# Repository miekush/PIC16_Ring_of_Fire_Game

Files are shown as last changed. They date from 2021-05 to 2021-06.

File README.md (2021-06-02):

# PIC16_Ring_of_Fire_Game
A PIC16 based LED Reaction Time Game

This is a simple LED reaction time game based on the classes light ring redemption games seen in arcades. 

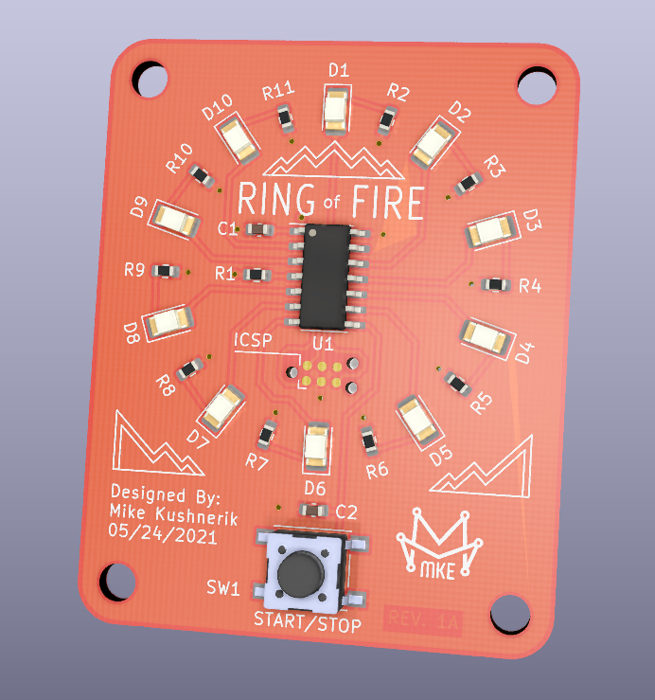
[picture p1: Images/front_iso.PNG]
PCB


# Project Description

The device uses a PIC16F15223 8-bit microcontroller to drive a ring of 1206 LEDs. A low cost tactile switch starts and stops the led chaser and allows for switching between game mode and a speed settings mode depending on the press duration. Programming the device is completed via the onboard Tag-Connect footprint.

# Breadboard Prototype

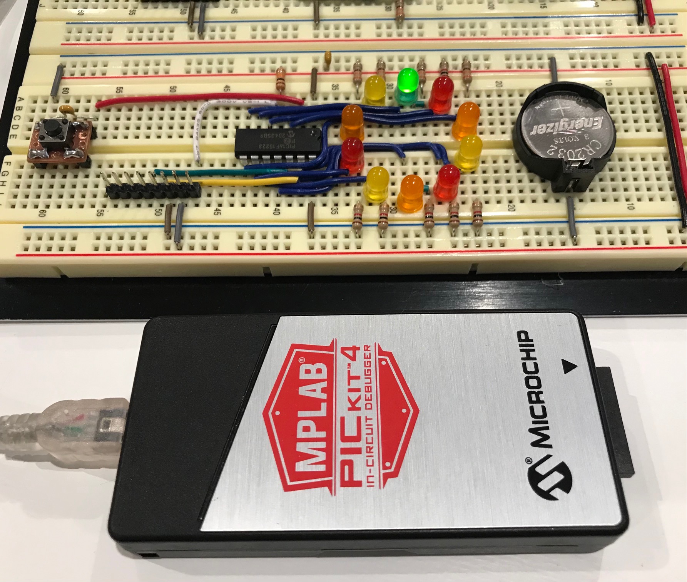
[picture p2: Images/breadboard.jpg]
Breadboard


# Enclosure

To make the device more comfortable for handheld use, I designed a small enclosure which can be easily 3D printed for a more professional device appearence.

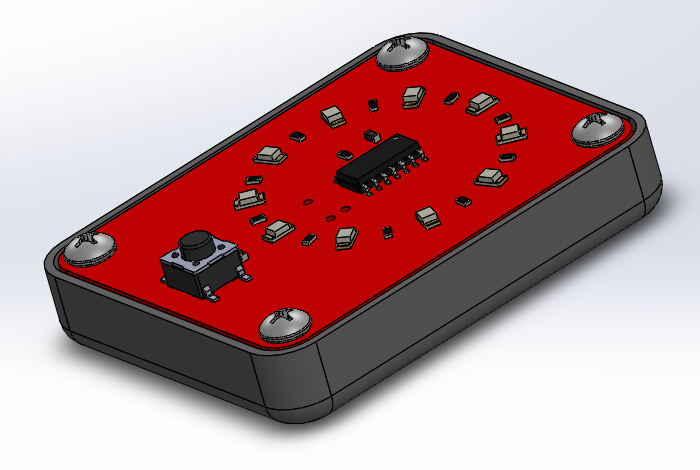
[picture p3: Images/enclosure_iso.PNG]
Enclosure


Designed by Mike Kushnerik (MKE) in KiCad V5

# License

MKE supports the open source hardware community by sharing hardware design files freely on GitHub!

Please support MKE by purchasing products on [Tindie](https://www.tindie.com/stores/mkengineering/)!

Designed by Mike Kushnerik for MKEngineering

Licensed under [Creative Commons Attribution-ShareAlike CC BY-SA 3.0](http://creativecommons.org/licenses/by-sa/3.0/)

All text above must be included in any redistribution!

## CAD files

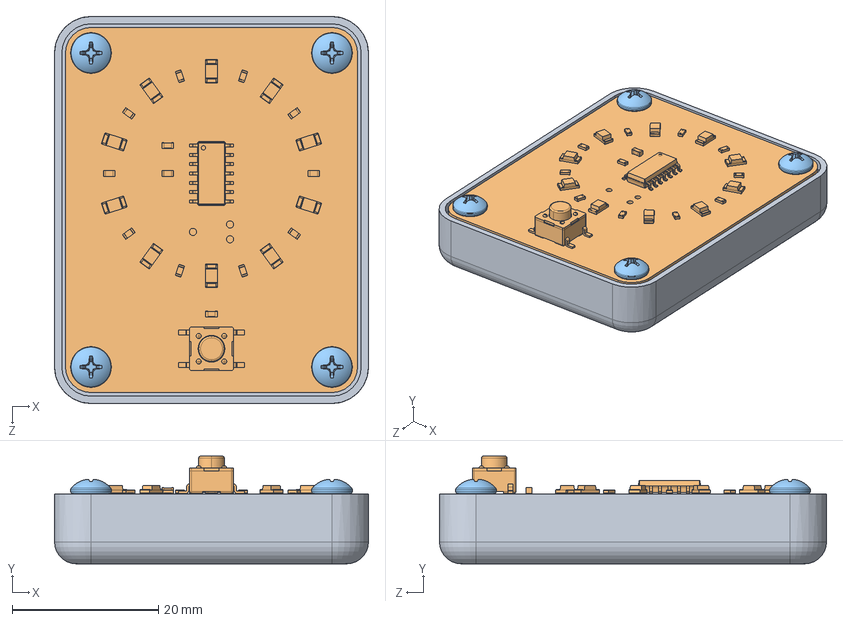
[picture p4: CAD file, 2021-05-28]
Enclosure/Revision 1/ring_of_fire_assembly_rev_1.SLDASM
43.0 x 14.8 x 53.0 mm
ring_of_fire_enclosure
ring_of_fire_pcba_rev_1a
92295A100_PHILLIPS THREAD-FORMING SCREW FOR PLASTIC x 4

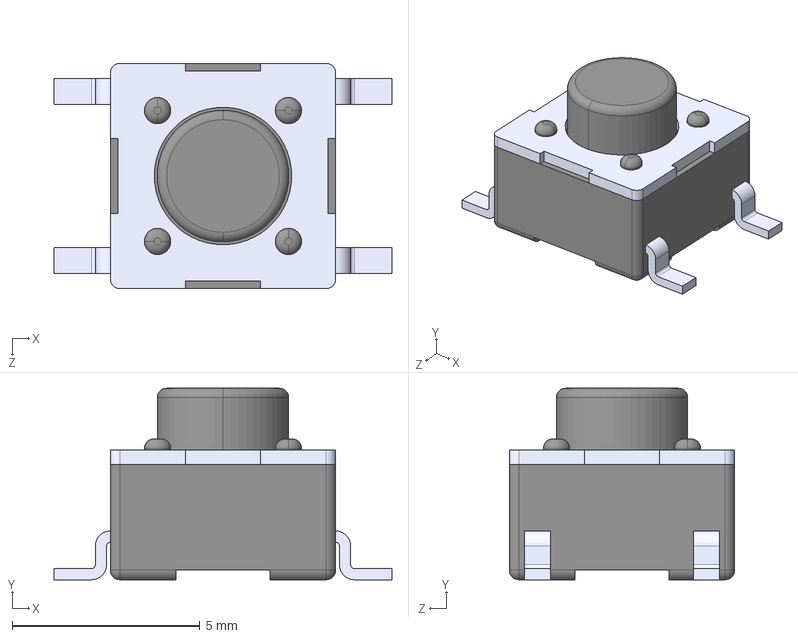
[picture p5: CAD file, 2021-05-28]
3D Models/PTS645SK50SMTR92LFS--3DModel-STEP-1.STEP
9.00 x 5.10 x 6.00 mm

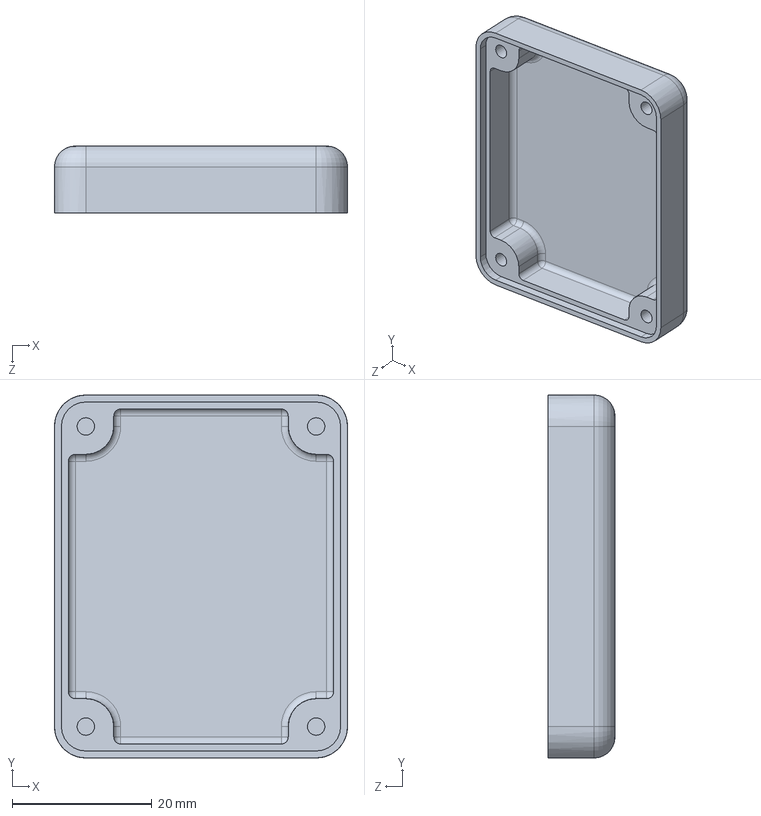
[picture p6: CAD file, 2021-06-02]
Enclosure/Revision 1/ring_of_fire_enclosure.SLDPRT
42.0 x 52.0 x 9.60 mm

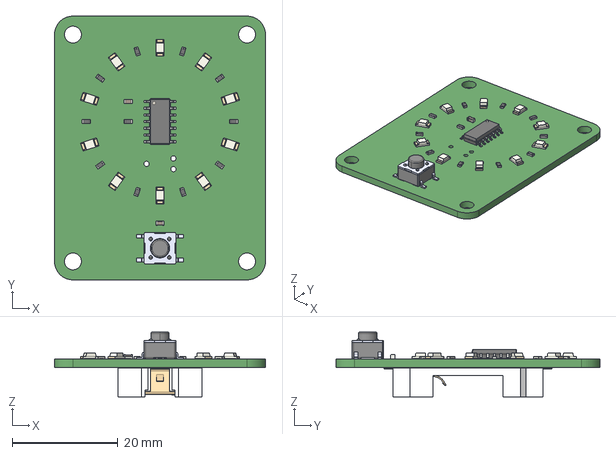
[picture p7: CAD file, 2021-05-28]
Enclosure/ring_of_fire_pcba_rev_1a.step
40.0 x 50.0 x 12.3 mm

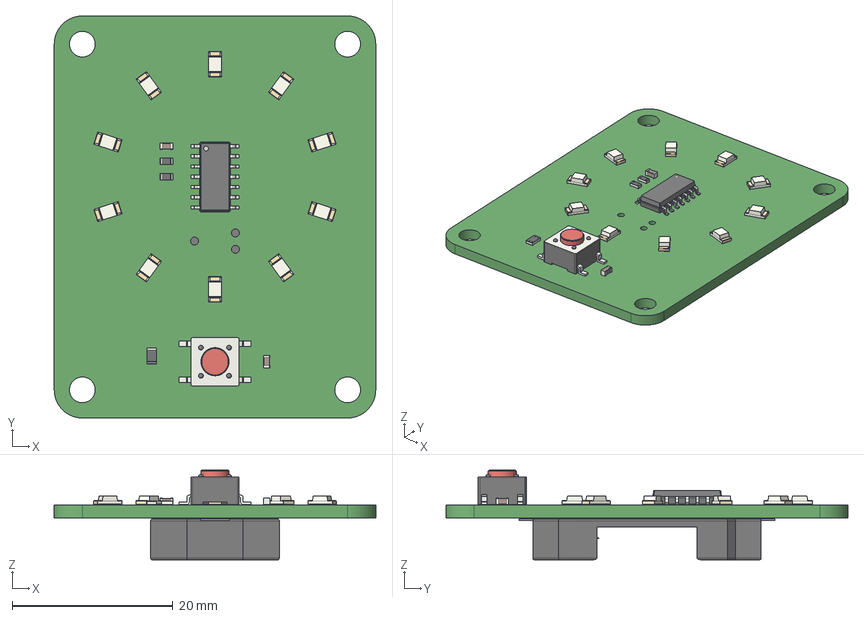
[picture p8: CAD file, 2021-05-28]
PIC16_Ring_of_Fire_Game.step
40.0 x 50.0 x 11.2 mm

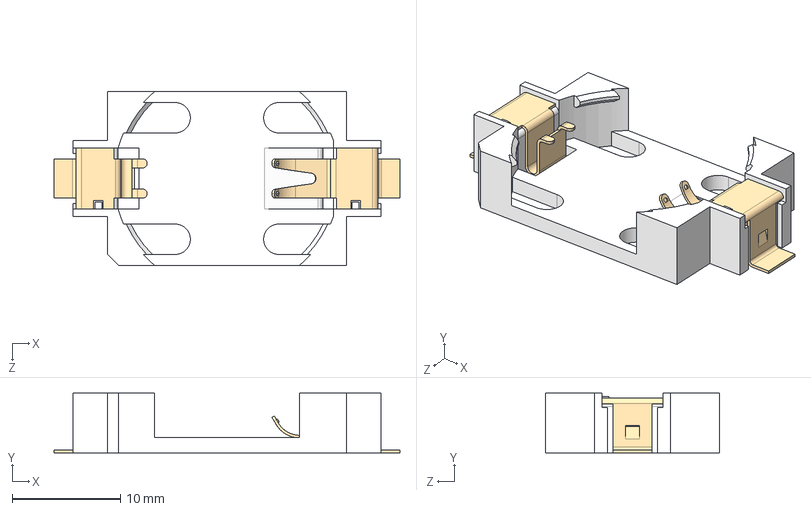
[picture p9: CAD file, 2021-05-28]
3D Models/1060TR--3DModel-STEP-1.STEP
31.9 x 5.51 x 16.0 mm

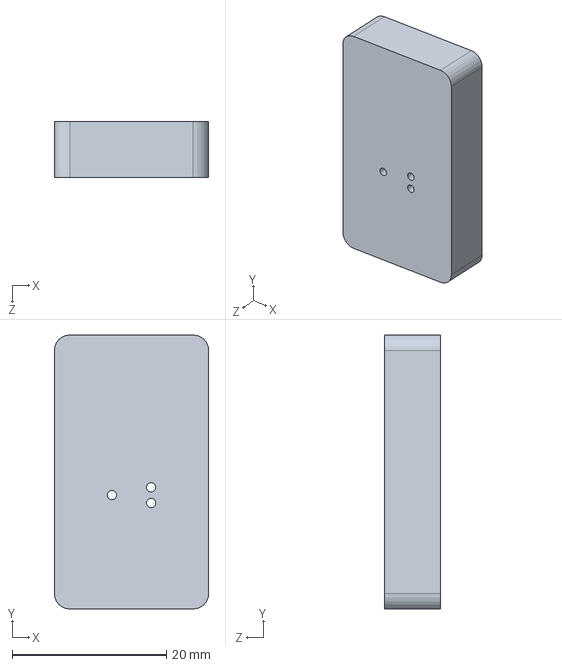
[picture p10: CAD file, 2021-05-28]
Enclosure/Revision 1/battery_drill_guide.SLDPRT
20.0 x 35.5 x 7.25 mm

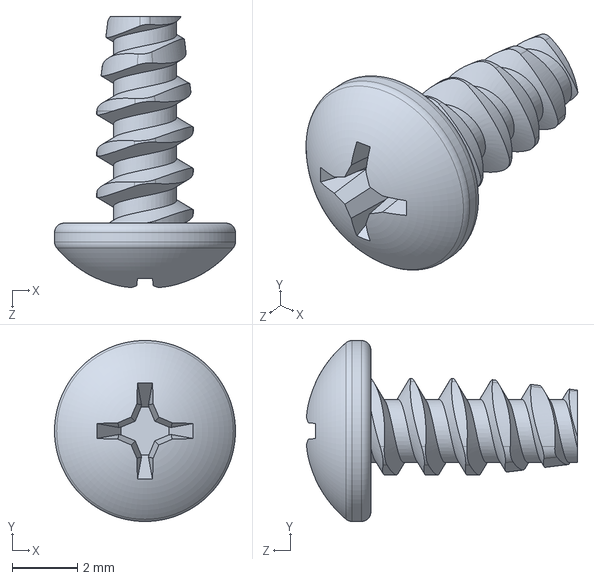
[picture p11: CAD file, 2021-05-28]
Enclosure/92295A100_PHILLIPS THREAD-FORMING SCREW FOR PLASTIC.SLDPRT
5.56 x 5.56 x 8.33 mm

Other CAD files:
Enclosure/Revision 1/battery_drill_guide.STL
Enclosure/Revision 1/ring_of_fire_enclosure.STL
Enclosure/ring_of_fire_pcba_rev_1a.SLDPRT
PIC16_Ring_of_Fire_Game.STL

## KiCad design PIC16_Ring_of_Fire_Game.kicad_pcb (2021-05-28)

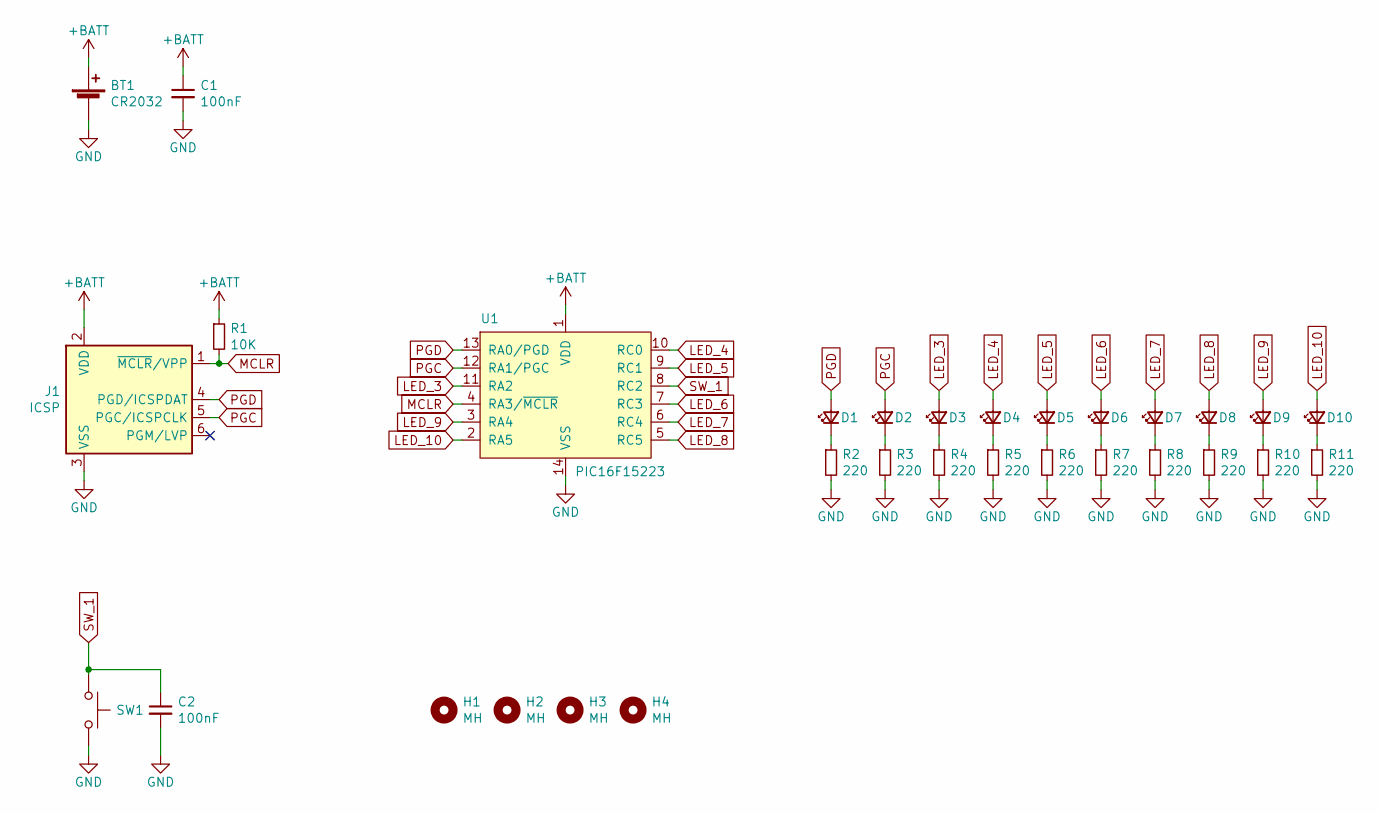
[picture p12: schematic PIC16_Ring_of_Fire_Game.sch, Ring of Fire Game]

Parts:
BT1: CR2032; 1060TR
C1, C2: 100nF; C_0603_1608Metric
D1, D2, D3, D4, D5, D6, D7, D8, D9, D10: 5mm LED; LED_1206_3216Metric
H1, H2, H3, H4: MH; MountingHole_3.2mm_M3
J1: ICSP; Tag-Connect_TC2030-IDC-NL_2x03_P1.27mm_Vertical
R1: 10K; R_0603_1608Metric
R2, R3, R4, R5, R6, R7, R8, R9, R10, R11: 220; R_0603_1608Metric
SW1: START/STOP; SW_SPST_PTS645
U1: PIC16F15223; SOIC-14_3.9x8.7mm_P1.27mm

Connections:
+BATT: BT1.1 (+), C1.1, J1.2 (VDD), R1.1, U1.1 (VDD)
GND: BT1.2 (-), C1.2, C2.2, J1.3 (VSS), R2.2, R3.2, R4.2, R5.2, R6.2, R7.2, R8.2, R9.2, R10.2, R11.2, SW1.1, U1.14 (VSS)
LED_3: D3.2 (A), U1.11 (RA2)
LED_4: D4.2 (A), U1.10 (RC0)
LED_5: D5.2 (A), U1.9 (RC1)
LED_6: D6.2 (A), U1.7 (RC3)
LED_7: D7.2 (A), U1.6 (RC4)
LED_8: D8.2 (A), U1.5 (RC5)
LED_9: D9.2 (A), U1.3 (RA4)
LED_10: D10.2 (A), U1.2 (RA5)
MCLR: J1.1 (~MCLR~/VPP), R1.2, U1.4 (RA3/~MCLR)
unnamed: D1.1 (K), R2.1
unnamed: D2.1 (K), R3.1
unnamed: D3.1 (K), R4.1
unnamed: D4.1 (K), R5.1
unnamed: D5.1 (K), R6.1
unnamed: D6.1 (K), R7.1
unnamed: D7.1 (K), R8.1
unnamed: D8.1 (K), R9.1
unnamed: D9.1 (K), R10.1
unnamed: D10.1 (K), R11.1
PGC: D2.2 (A), J1.5 (PGC/ICSPCLK), U1.12 (RA1/PGC)
PGD: D1.2 (A), J1.4 (PGD/ICSPDAT), U1.13 (RA0/PGD)
SW_1: C2.1, SW1.2, U1.8 (RC2)

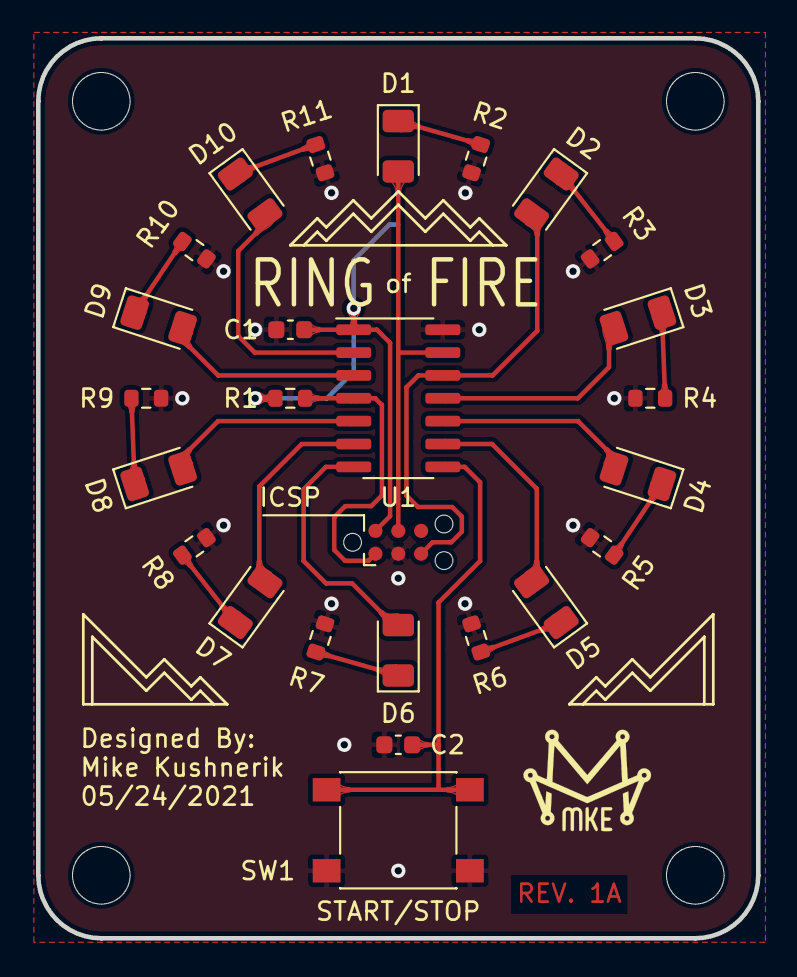
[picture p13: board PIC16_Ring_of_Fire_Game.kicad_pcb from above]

Board: 2 copper layers, 40.0 x 50.0 mm, 31 parts (1 on the bottom side), 24 nets.

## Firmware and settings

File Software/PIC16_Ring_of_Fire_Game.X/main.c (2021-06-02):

//Ring of Fire LED Game
//Device: PIC16F15223
//File: main.c
//Author: Mike Kushnerik
//Date: 5/19/21

#include "mcc_generated_files/mcc.h"

//global variables
int ledReg = 0b0000000001, 
    speedReg = 0b0000000000;
int gameState = 0,
    ledPeriod = 50, //initially at 50% speed
    ledCount = 0, 
    blinkCount = 0, 
    buttonCount = 0, 
    buttonDuration;
//flag for button press
bool buttonFlag = false;

//function prototypes
void timerISR(void);
void buttonISR(void);
void processButton(void);

//main function
void main(void)
{
    //initialize the device
    SYSTEM_Initialize();
    
    //register interrupt handlers
    TMR0_SetInterruptHandler(timerISR);
    TMR2_SetInterruptHandler(buttonISR);

    //enable interrupts
    INTERRUPT_GlobalInterruptEnable();
    INTERRUPT_PeripheralInterruptEnable();
    
    //enter sleep mode
    SLEEP();

    //main loop
    while (1)
    {
        if(buttonFlag)
        {
            processButton();
        }
        //determine current game state
        switch(gameState)
        {
            case 0: //game inactive
                if(blinkCount > 250) //250 ms
                {
                    //toggle active led
                    PORTA ^= (ledReg & 0b000111)|((ledReg >> 4) & 0b110000);
                    PORTC ^= ((ledReg >> 3) & 0b000011)|((ledReg >> 2) & 0b111000);
                    //reset counter
                    blinkCount = 0;
                }
                break;
            case 1: //game active
                if(ledCount > ledPeriod)
                {
                    //shift leds
                    ledReg = ledReg << 1;
                    //reset register
                    if(ledReg > 0b1000000000) ledReg = 0b0000000001;
                    /*
                    //write led pins
                    PORTA = (ledReg & 0b000111)|((ledReg >> 5) & 0b010000);
                    PORTC = ((ledReg >> 3) & 0b111111);
                    */
                    //write led pins
                    PORTA = (ledReg & 0b000111)|((ledReg >> 4) & 0b110000);
                    PORTC = ((ledReg >> 3) & 0b000011)|((ledReg >> 2) & 0b111000);
                     
                    //reset counter
                    ledCount = 0;
                }
                break;
            case 2: //game settings
                //write led speed to register for bargraph
                speedReg = 0;
                for(int i = 0; i < 11 - (ledPeriod / 10); i++)
                {
                  speedReg |= 1 << i;
                }
                //write led pins
                PORTA = (speedReg & 0b000111)|((speedReg >> 4) & 0b110000);
                PORTC = ((speedReg >> 3) & 0b000011)|((speedReg >> 2) & 0b111000);
                break;
            default:
                break;
        }
    }
}

//timer isr to increment counters every 1 ms
void timerISR (void)
{
    ledCount++;
    blinkCount++;
    buttonCount++;
}

//isr to capture button press
void buttonISR (void)
{
    //clear watchdog timer
    CLRWDT();
    //determine press duration
    if(!RC2) //button pressed
    {
        buttonCount = 0;
    }
    else //button released
    {
        buttonDuration = buttonCount;
        buttonFlag = true;
    }
}

//function to process button press
void processButton(void)
{
    //reset flag
    buttonFlag = false;
    //process button
    if(buttonDuration < 3000) //short press
    {
        //determine task
        switch(gameState)
        {
            case 0:
                ledCount = 0;
                gameState = 1;
                break;
            case 1:
                blinkCount = 0;
                gameState = 0;
                break;
            case 2:
                //decrement led period by 10 ms
                ledPeriod -= 10;
                //reset to lowest value
                if(ledPeriod < 10) ledPeriod = 100;
                break;
            default:
                break;
        }
    }
    else //long press
    {
        //determine task
        switch(gameState)
        {
            case 0:
                gameState = 2;
                break;
            case 1:
                gameState = 2;
                break;
            case 2:
                ledCount = 0;
                gameState = 1;
                break;
            default:
                break;
        }
    }
    //reset press duration
    buttonDuration = 0;
}

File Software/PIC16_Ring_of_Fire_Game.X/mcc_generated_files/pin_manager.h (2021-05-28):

/**
  @Generated Pin Manager Header File

  @Company:
    Microchip Technology Inc.

  @File Name:
    pin_manager.h

  @Summary:
    This is the Pin Manager file generated using PIC10 / PIC12 / PIC16 / PIC18 MCUs

  @Description
    This header file provides APIs for driver for .
    Generation Information :
        Product Revision  :  PIC10 / PIC12 / PIC16 / PIC18 MCUs - 1.81.7
        Device            :  PIC16F15223
        Driver Version    :  2.11
    The generated drivers are tested against the following:
        Compiler          :  XC8 2.31 and above
        MPLAB 	          :  MPLAB X 5.45	
*/

/*
    (c) 2018 Microchip Technology Inc. and its subsidiaries. 
    
    Subject to your compliance with these terms, you may use Microchip software and any 
    derivatives exclusively with Microchip products. It is your responsibility to comply with third party 
    license terms applicable to your use of third party software (including open source software) that 
    may accompany Microchip software.
    
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
    IN NO EVENT WILL MICROCHIP BE LIABLE FOR ANY INDIRECT, SPECIAL, PUNITIVE, 
    INCIDENTAL OR CONSEQUENTIAL LOSS, DAMAGE, COST OR EXPENSE OF ANY KIND 
    WHATSOEVER RELATED TO THE SOFTWARE, HOWEVER CAUSED, EVEN IF MICROCHIP 
    HAS BEEN ADVISED OF THE POSSIBILITY OR THE DAMAGES ARE FORESEEABLE. TO 
    THE FULLEST EXTENT ALLOWED BY LAW, MICROCHIP'S TOTAL LIABILITY ON ALL 
    CLAIMS IN ANY WAY RELATED TO THIS SOFTWARE WILL NOT EXCEED THE AMOUNT 
    OF FEES, IF ANY, THAT YOU HAVE PAID DIRECTLY TO MICROCHIP FOR THIS 
    SOFTWARE.
*/

#ifndef PIN_MANAGER_H
#define PIN_MANAGER_H

/**
  Section: Included Files
*/

#include <xc.h>

#define INPUT   1
#define OUTPUT  0

#define HIGH    1
#define LOW     0

#define ANALOG      1
#define DIGITAL     0

#define PULL_UP_ENABLED      1
#define PULL_UP_DISABLED     0

// get/set LED_1 aliases
#define LED_1_TRIS                 TRISAbits.TRISA0
#define LED_1_LAT                  LATAbits.LATA0
#define LED_1_PORT                 PORTAbits.RA0
#define LED_1_WPU                  WPUAbits.WPUA0
#define LED_1_OD                   ODCONAbits.ODCA0
#define LED_1_ANS                  ANSELAbits.ANSA0
#define LED_1_SetHigh()            do { LATAbits.LATA0 = 1; } while(0)
#define LED_1_SetLow()             do { LATAbits.LATA0 = 0; } while(0)
#define LED_1_Toggle()             do { LATAbits.LATA0 = ~LATAbits.LATA0; } while(0)
#define LED_1_GetValue()           PORTAbits.RA0
#define LED_1_SetDigitalInput()    do { TRISAbits.TRISA0 = 1; } while(0)
#define LED_1_SetDigitalOutput()   do { TRISAbits.TRISA0 = 0; } while(0)
#define LED_1_SetPullup()          do { WPUAbits.WPUA0 = 1; } while(0)
#define LED_1_ResetPullup()        do { WPUAbits.WPUA0 = 0; } while(0)
#define LED_1_SetPushPull()        do { ODCONAbits.ODCA0 = 0; } while(0)
#define LED_1_SetOpenDrain()       do { ODCONAbits.ODCA0 = 1; } while(0)
#define LED_1_SetAnalogMode()      do { ANSELAbits.ANSA0 = 1; } while(0)
#define LED_1_SetDigitalMode()     do { ANSELAbits.ANSA0 = 0; } while(0)

// get/set LED_2 aliases
#define LED_2_TRIS                 TRISAbits.TRISA1
#define LED_2_LAT                  LATAbits.LATA1
#define LED_2_PORT                 PORTAbits.RA1
#define LED_2_WPU                  WPUAbits.WPUA1
#define LED_2_OD                   ODCONAbits.ODCA1
#define LED_2_ANS                  ANSELAbits.ANSA1
#define LED_2_SetHigh()            do { LATAbits.LATA1 = 1; } while(0)
#define LED_2_SetLow()             do { LATAbits.LATA1 = 0; } while(0)
#define LED_2_Toggle()             do { LATAbits.LATA1 = ~LATAbits.LATA1; } while(0)
#define LED_2_GetValue()           PORTAbits.RA1
#define LED_2_SetDigitalInput()    do { TRISAbits.TRISA1 = 1; } while(0)
#define LED_2_SetDigitalOutput()   do { TRISAbits.TRISA1 = 0; } while(0)
#define LED_2_SetPullup()          do { WPUAbits.WPUA1 = 1; } while(0)
#define LED_2_ResetPullup()        do { WPUAbits.WPUA1 = 0; } while(0)
#define LED_2_SetPushPull()        do { ODCONAbits.ODCA1 = 0; } while(0)
#define LED_2_SetOpenDrain()       do { ODCONAbits.ODCA1 = 1; } while(0)
#define LED_2_SetAnalogMode()      do { ANSELAbits.ANSA1 = 1; } while(0)
#define LED_2_SetDigitalMode()     do { ANSELAbits.ANSA1 = 0; } while(0)

// get/set LED_3 aliases
#define LED_3_TRIS                 TRISAbits.TRISA2
#define LED_3_LAT                  LATAbits.LATA2
#define LED_3_PORT                 PORTAbits.RA2
#define LED_3_WPU                  WPUAbits.WPUA2
#define LED_3_OD                   ODCONAbits.ODCA2
#define LED_3_ANS                  ANSELAbits.ANSA2
#define LED_3_SetHigh()            do { LATAbits.LATA2 = 1; } while(0)
#define LED_3_SetLow()             do { LATAbits.LATA2 = 0; } while(0)
#define LED_3_Toggle()             do { LATAbits.LATA2 = ~LATAbits.LATA2; } while(0)
#define LED_3_GetValue()           PORTAbits.RA2
#define LED_3_SetDigitalInput()    do { TRISAbits.TRISA2 = 1; } while(0)
#define LED_3_SetDigitalOutput()   do { TRISAbits.TRISA2 = 0; } while(0)
#define LED_3_SetPullup()          do { WPUAbits.WPUA2 = 1; } while(0)
#define LED_3_ResetPullup()        do { WPUAbits.WPUA2 = 0; } while(0)
#define LED_3_SetPushPull()        do { ODCONAbits.ODCA2 = 0; } while(0)
#define LED_3_SetOpenDrain()       do { ODCONAbits.ODCA2 = 1; } while(0)
#define LED_3_SetAnalogMode()      do { ANSELAbits.ANSA2 = 1; } while(0)
#define LED_3_SetDigitalMode()     do { ANSELAbits.ANSA2 = 0; } while(0)

// get/set LED_10 aliases
#define LED_10_TRIS                 TRISAbits.TRISA4
#define LED_10_LAT                  LATAbits.LATA4
#define LED_10_PORT                 PORTAbits.RA4
#define LED_10_WPU                  WPUAbits.WPUA4
#define LED_10_OD                   ODCONAbits.ODCA4
#define LED_10_ANS                  ANSELAbits.ANSA4
#define LED_10_SetHigh()            do { LATAbits.LATA4 = 1; } while(0)
#define LED_10_SetLow()             do { LATAbits.LATA4 = 0; } while(0)
#define LED_10_Toggle()             do { LATAbits.LATA4 = ~LATAbits.LATA4; } while(0)
#define LED_10_GetValue()           PORTAbits.RA4
#define LED_10_SetDigitalInput()    do { TRISAbits.TRISA4 = 1; } while(0)
#define LED_10_SetDigitalOutput()   do { TRISAbits.TRISA4 = 0; } while(0)
#define LED_10_SetPullup()          do { WPUAbits.WPUA4 = 1; } while(0)
#define LED_10_ResetPullup()        do { WPUAbits.WPUA4 = 0; } while(0)
#define LED_10_SetPushPull()        do { ODCONAbits.ODCA4 = 0; } while(0)
#define LED_10_SetOpenDrain()       do { ODCONAbits.ODCA4 = 1; } while(0)
#define LED_10_SetAnalogMode()      do { ANSELAbits.ANSA4 = 1; } while(0)
#define LED_10_SetDigitalMode()     do { ANSELAbits.ANSA4 = 0; } while(0)
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

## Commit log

2021-05-28 Initial Upload
    [1060TR--3DModel-STEP-1.STEP, 92295A100_PHILLIPS THREAD-FORMING SCREW FOR PLASTIC.SLDPRT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]
2021-06-02 Update LED pins to match PCB
